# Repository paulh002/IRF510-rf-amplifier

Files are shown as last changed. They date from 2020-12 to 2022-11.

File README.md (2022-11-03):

# IRF510-rf-amplifier

This amplifier was designed as a pspice simulation project. Later I have build and tested it.
The goal was to see if sources of distortion could be found and how certain components infuence the linearity of the amplifier.
In the simulation schematic extra components are added to simulate loss in the transformers. Changing these loss components give rise to more or less distrortion
There are 2 versions of the PCB in Kicad direcory IRF510 is used in RD16HFF directory the RD16HFF is used, this Fet has a different layout, so take care to choose the correct version.
With R6 and R11 you can control the gain. R9 and R14 are there to add extra stability. You can experiment with the values or make R9 and R14 0 ohm.

Small 10 to 20 Watt ampliefier (2 - 30 Mhz) with driver

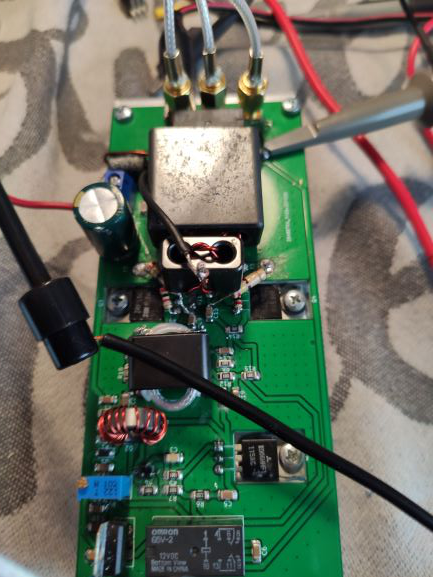
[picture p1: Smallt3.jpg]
VFO


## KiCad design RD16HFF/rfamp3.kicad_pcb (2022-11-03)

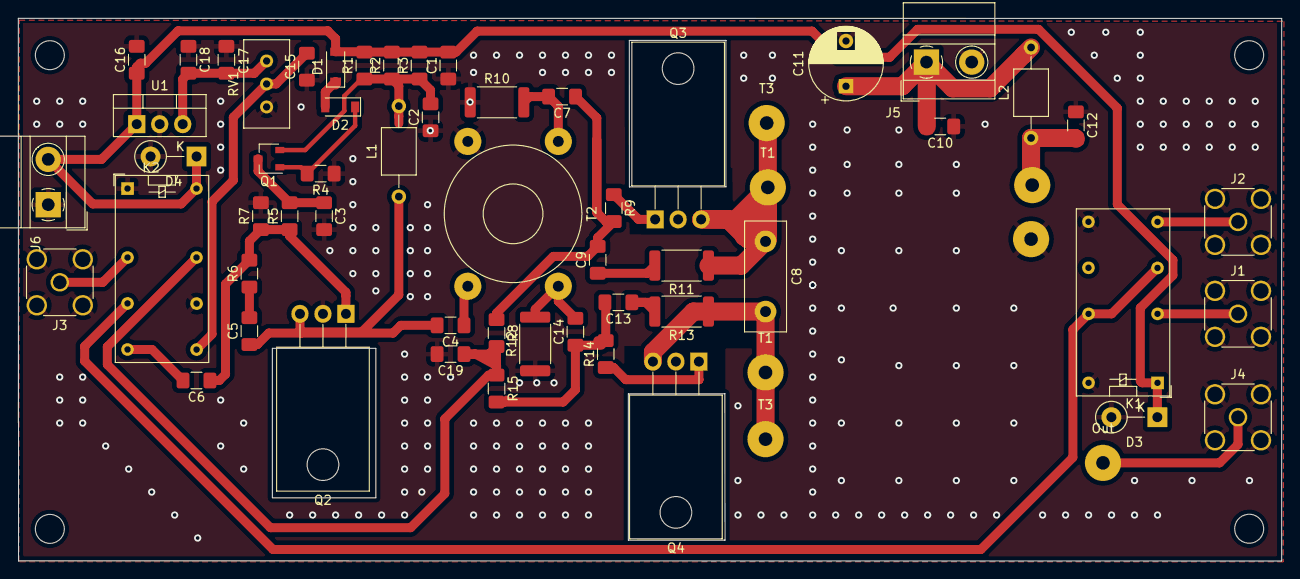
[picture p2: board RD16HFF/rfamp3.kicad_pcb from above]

Board: 2 copper layers, 139.6 x 60.0 mm, 66 parts (0 on the bottom side), 31 nets.

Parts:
 : SolderWirePad_1x01_Drill1.5mm
 #2: SolderWirePad_1x01_Drill1.5mm
 #3,  #4,  #5,  #6: MountingHole_3.2mm_M3
C1, C2, C4, C5, C6, C7, C9, C10, C12, C13, C14, C15, C18, C19: 100n; C_1206_3216Metric_Pad1.42x1.75mm_HandSolder
C3: 1u; C_1206_3216Metric_Pad1.42x1.75mm_HandSolder
C8: 500p; C_Disc_D12.0mm_W4.4mm_P7.75mm
C11: 100u; CP_Radial_D8.0mm_P5.00mm
C16, C17: 10u; C_1206_3216Metric_Pad1.42x1.75mm_HandSolder
D1, D2: D; D_SOD-123
D3, D4: D; D_DO-41_SOD81_P5.08mm_Vertical_KathodeUp
J1, J3: Conn_Coaxial; SMA_Amphenol_132134_Vertical
J2: LPF-Out; SMA_Amphenol_132134_Vertical
J4: LPF; SMA_Amphenol_132134_Vertical
J5: 12V Power; TerminalBlock_MetzConnect_Type011_RT05502HBWC_1x02_P5.00mm_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
J6: 12V Switch; TerminalBlock_MetzConnect_Type011_RT05502HBWC_1x02_P5.00mm_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
K1, K2: G5V-2; Relay_DPDT_Omron_G5V-2
L1, L2: 100u; L_Axial_L5.0mm_D3.6mm_P10.00mm_Horizontal_Murata_BL01RN1A2A2
Out: SolderWirePad_1x01_Drill1.5mm
Q1: 2N3906; SOT-23W
Q2: RD06HHF; TO-220-3_Horizontal_TabDown
Q3: RD16HHF; TO-220-3_Horizontal_TabDown
Q4: RD16HFF; TO-220-3_Horizontal_TabDown
R1, R2, R3: 10; R_1206_3216Metric_Pad1.42x1.75mm_HandSolder
R4, R5, R7, R8, R15: 1k; R_1206_3216Metric_Pad1.42x1.75mm_HandSolder
R6: 560; R_1206_3216Metric_Pad1.42x1.75mm_HandSolder
R9, R14: 4.7; R_1206_3216Metric_Pad1.42x1.75mm_HandSolder
R10: 22; R_2512_6332Metric
R11, R13: 220; R_2512_6332Metric
R12: 10; R_2512_6332Metric
RV1: R_POT; Potentiometer_Bourns_3296W_Vertical
T1, T1#2, T3, T3#2: SolderWirePad_1x01_Drill1.5mm
T2: Transformer_1P_1S; Transformer_Toroid_Horizontal_D14.0mm_Amidon-T50
U1: L7805; TO-220-3_Vertical

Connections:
12V_Switch: C1.2, C16.1, D1.2 (A), D3.1 (K), D4.1 (K), J6.2, K1.1, K2.16, R1.2, R2.2, R3.2, U1.1 (IN)
Bias_A: C19.1, K2.13, R8.2, R15.1
GND: .1, C1.1, C2.1, C3.2, C10.1, C11.2, C12.1, C15.1, C16.2, C17.2, C18.1, C19.2, D3.2 (A), D4.2 (A), J1.2 (Ext), J2.2 (Ext), J3.2 (Ext), J4.2 (Ext), J5.2, J6.1, K1.9, K1.16, K2.1, K2.11, Q2.2 (S), Q3.2 (S), Q4.2 (S), R4.1, R7.2, R10.1, R12.1, RV1.3, T2.1 (AA), U1.2 (GND)
unnamed: C2.2, L1.2, Q1.2 (E), R1.1, R2.1, R3.1
unnamed: C3.1, Q1.3 (C), R5.2
unnamed: C4.1, T2.2 (AB)
unnamed: C4.2, C5.1, L1.1, Q2.3 (D)
unnamed: C5.2, R6.1
unnamed: C6.1, Q2.1 (G), R5.1, R6.2, R7.1
unnamed: C6.2, K2.8
unnamed: C7.1, C9.2, R8.1, R9.2
unnamed: C7.2, R10.2, T2.3 (SA)
unnamed: C8.1, Q3.3 (D), R11.1, T1#2.1, T3.1
unnamed: C8.2, Q4.3 (D), R13.1, T1.1, T3#2.1
unnamed: C9.1, R11.2
unnamed: C10.2, C11.1, J5.1, L2.2
unnamed: #2.1, C12.2, L2.1
unnamed: C13.1, R13.2
unnamed: C13.2, C14.1, R14.2, R15.2
unnamed: C14.2, R12.2, T2.4 (SB)
unnamed: C15.2, K2.9, RV1.2
unnamed: C17.1, C18.2, RV1.1, U1.3 (OUT)
unnamed: D1.1 (K), D2.2 (A)
unnamed: D2.1 (K), Q1.1 (B), R4.2
unnamed: J1.1 (In), K1.4
unnamed: J2.1 (In), K1.8
unnamed: J3.1 (In), K2.4
unnamed: J4.1 (In), Out.1
unnamed: K1.6, K1.13, K2.6
unnamed: Q3.1 (G), R9.1
unnamed: Q4.1 (G), R14.1

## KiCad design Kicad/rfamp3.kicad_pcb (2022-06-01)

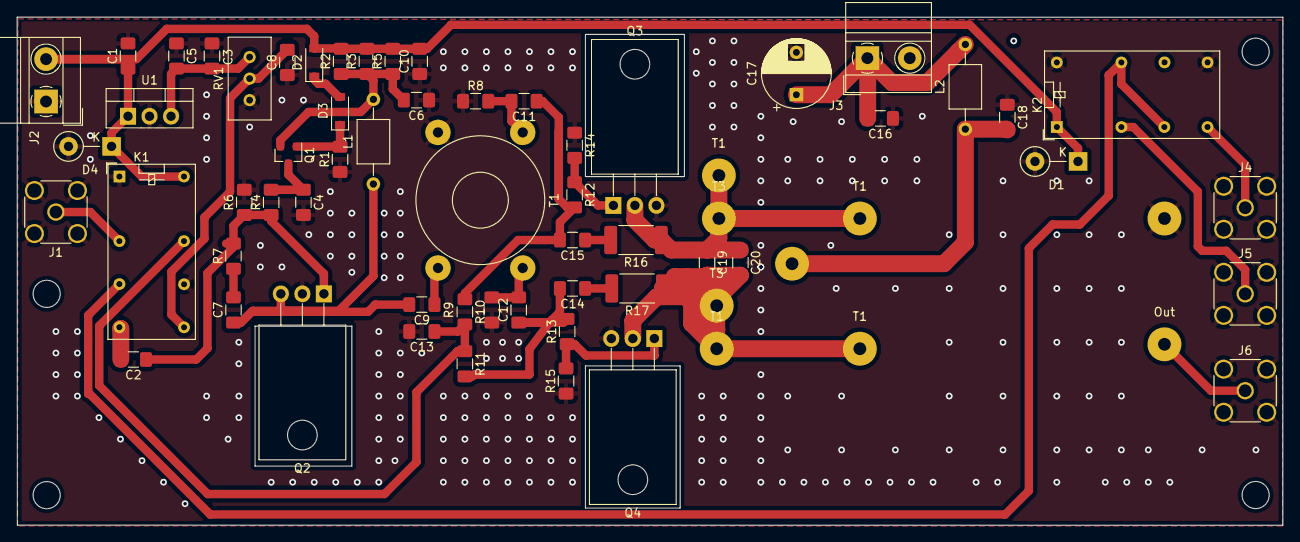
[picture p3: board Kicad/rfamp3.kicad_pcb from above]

Board: 2 copper layers, 149.4 x 60.0 mm, 71 parts (0 on the bottom side), 32 nets.

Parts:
 : MountingHole_3.2mm_M3
 #2,  #3,  #4: MountingHole_3.2mm_M3
 #5,  #6: SolderWirePad_1x01_Drill1.5mm
C1, C3: 10u; C_1206_3216Metric_Pad1.42x1.75mm_HandSolder
C2, C5, C6, C7, C8, C9, C10, C11, C12, C13, C14, C15, C16, C18: 100n; C_1206_3216Metric_Pad1.42x1.75mm_HandSolder
C4: 1u; C_1206_3216Metric_Pad1.42x1.75mm_HandSolder
C17: 100u; CP_Radial_D8.0mm_P5.00mm
C19, C20: 500p; C_1206_3216Metric_Pad1.42x1.75mm_HandSolder
D1, D4: 1n4007; D_DO-41_SOD81_P5.08mm_Vertical_KathodeUp
D2, D3: D; D_SOD-123
J1, J5: Conn_Coaxial; SMA_Amphenol_132134_Vertical
J2: 12V Switch; TerminalBlock_MetzConnect_Type011_RT05502HBWC_1x02_P5.00mm_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
J3: 12V Power; TerminalBlock_MetzConnect_Type011_RT05502HBWC_1x02_P5.00mm_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
J4: LPF-Out; SMA_Amphenol_132134_Vertical
J6: LPF; SMA_Amphenol_132134_Vertical
K1, K2: G5V-2; Relay_DPDT_Omron_G5V-2
L1, L2: 100u; L_Axial_L5.0mm_D3.6mm_P10.00mm_Horizontal_Murata_BL01RN1A2A2
Out: SolderWirePad_1x01_Drill1.5mm
Q1: 2N3906; SOT-23
Q2: RD6HHF1; TO-220-3_Horizontal_TabDown
Q3, Q4: IRF510; TO-220-3_Horizontal_TabDown
R1, R4, R6, R10, R11, R14, R15: 1k; R_1206_3216Metric_Pad1.42x1.75mm_HandSolder
R2, R3, R5, R8, R9: 10; R_1206_3216Metric_Pad1.42x1.75mm_HandSolder
R7: 560; R_1206_3216Metric_Pad1.42x1.75mm_HandSolder
R12, R13: 1; R_1206_3216Metric_Pad1.42x1.75mm_HandSolder
R16, R17: 220; R_2512_6332Metric_Pad1.52x3.35mm_HandSolder
RV1: R_POT; Potentiometer_Bourns_3296W_Vertical
T1: Transformer_1P_1S; Transformer_Toroid_Horizontal_D14.0mm_Amidon-T50
T1#2, T1#3, T1#4, T1#5, T3, T3#2: SolderWirePad_1x01_Drill1.5mm
U1: L7805; TO-220-3_Vertical

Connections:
12V_Switch: C1.1, C10.2, D1.1 (K), D2.2 (A), D4.1 (K), J2.2, K1.16, K2.1, R2.2, R3.2, R5.2, U1.1 (IN)
Bias_A: C13.1, K1.13, R10.2, R11.1
GND: #5.1, C1.2, C3.2, C4.2, C5.1, C6.1, C8.1, C10.1, C13.2, C16.1, C17.2, C18.1, D1.2 (A), D4.2 (A), J1.2 (Ext), J2.1, J3.2, J4.2 (Ext), J5.2 (Ext), J6.2 (Ext), K1.1, K1.11, K2.9, K2.16, Q2.2 (S), Q3.3 (S), Q4.3 (S), R1.1, R6.2, R8.1, R9.1, R14.1, R15.1, RV1.3, T1.1 (AA), U1.2 (GND)
unnamed: C2.1, Q2.1 (G), R4.1, R6.1, R7.2
unnamed: C2.2, K1.8
unnamed: C3.1, C5.2, RV1.1, U1.3 (OUT)
unnamed: C4.1, Q1.3 (C), R4.2
unnamed: C6.2, L1.2, Q1.2 (E), R2.1, R3.1, R5.1
unnamed: C7.1, C9.2, L1.1, Q2.3 (D)
unnamed: C7.2, R7.1
unnamed: C8.2, K1.9, RV1.2
unnamed: C9.1, T1.2 (AB)
unnamed: C11.1, C15.2, R10.1, R12.2
unnamed: C11.2, R8.2, T1.3 (SA)
unnamed: C12.1, C14.2, R11.2, R13.2
unnamed: #6.1, C12.2, R9.2, T1.4 (SB)
unnamed: C14.1, R17.2
unnamed: C15.1, R16.2
unnamed: C16.2, C17.1, J3.1, L2.2
unnamed: C18.2, L2.1
unnamed: C19.1, C20.1, Q3.2 (D), R16.1
unnamed: C19.2, C20.2, Q4.2 (D), R17.1
unnamed: T1#3.1, T1#4.1, T3.1
unnamed: T1#2.1, T1#5.1, T3#2.1
unnamed: D2.1 (K), D3.2 (A)
unnamed: D3.1 (K), Q1.1 (B), R1.2
unnamed: J1.1 (In), K1.4
unnamed: J4.1 (In), K2.8, Out.1
unnamed: J5.1 (In), K2.4
unnamed: K1.6, K2.6, K2.13
unnamed: Q3.1 (G), R12.1, R14.2
unnamed: Q4.1 (G), R13.1, R15.2

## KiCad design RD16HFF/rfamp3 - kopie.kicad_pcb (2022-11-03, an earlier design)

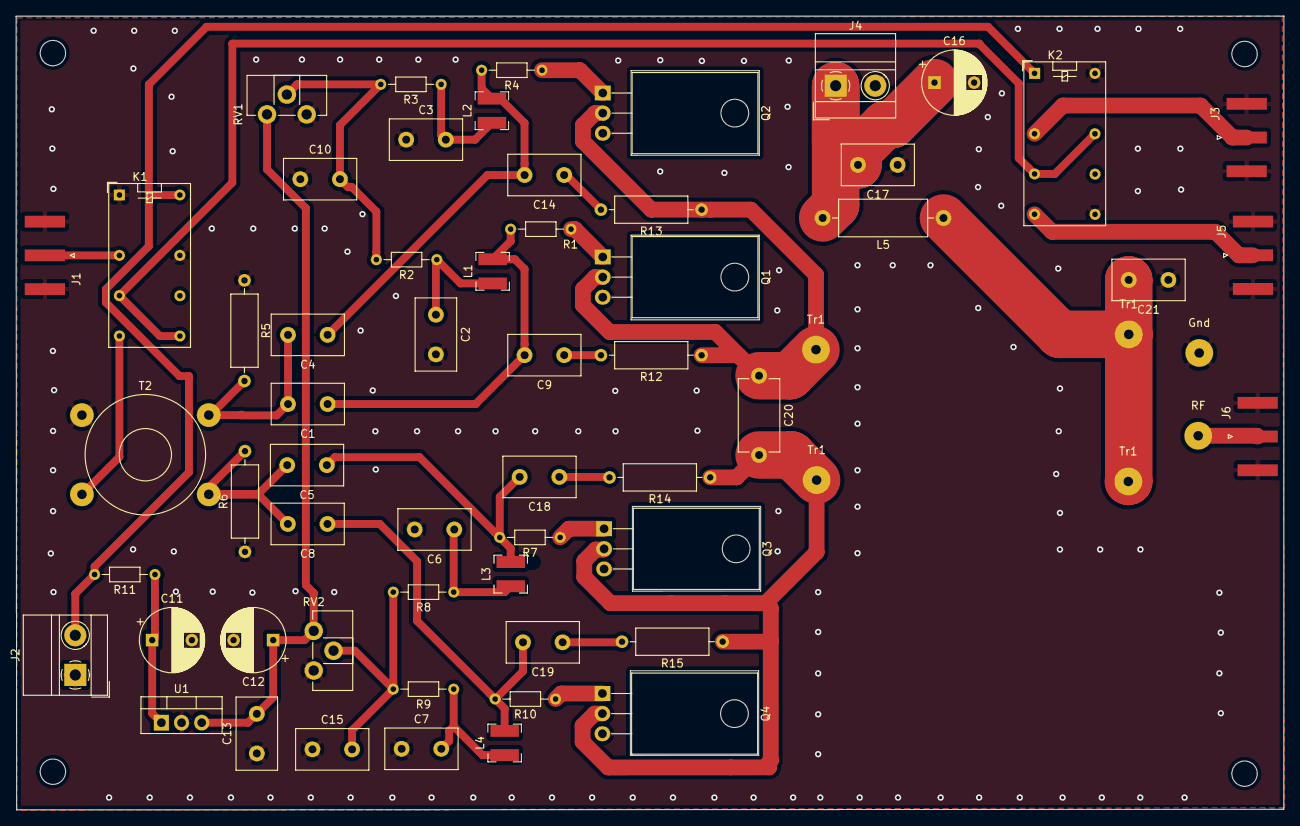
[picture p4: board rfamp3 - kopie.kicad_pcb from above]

Board: 2 copper layers, 159.9 x 100.1 mm, 67 parts (0 on the bottom side), 34 nets.

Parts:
 : MountingHole_3.2mm_M3
 #2,  #3,  #4: MountingHole_3.2mm_M3
C1, C2, C3, C4, C5, C6, C7, C8, C9, C10, C13, C14, C15, C17, C18, C19, C21: 100n; C_Disc_D9.0mm_W5.0mm_P5.00mm
C11, C12: 10u; CP_Radial_D8.0mm_P5.00mm
C16: 100u; CP_Radial_D8.0mm_P5.00mm
C20: 500p; C_Disc_D9.0mm_W5.0mm_P10.00mm
Gnd: Gnd; SolderWirePad_1x01_Drill1.2mm
J1, J3: Conn_Coaxial; SMA_Amphenol_132289_EdgeMount
J2: 12V Switch; TerminalBlock_MetzConnect_Type011_RT05502HBWC_1x02_P5.00mm_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
J4: 12V Power; TerminalBlock_MetzConnect_Type011_RT05502HBWC_1x02_P5.00mm_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
J5: LPF-Out; SMA_Amphenol_132289_EdgeMount
J6: LPF; SMA_Amphenol_132289_EdgeMount
K1, K2: G5V-2; Relay_DPDT_Omron_G5V-2
L1, L2, L3, L4: 100u; L_Bourns-SRN4018
L5: 100u; L_Axial_L11.0mm_D4.5mm_P15.24mm_Horizontal_Fastron_MECC
Q1, Q2, Q3, Q4: IRFN24; TO-220-3_Horizontal_TabDown
R1, R4, R7, R10: 4.7; R_Axial_DIN0204_L3.6mm_D1.6mm_P7.62mm_Horizontal
R2, R3, R8, R9: 47; R_Axial_DIN0204_L3.6mm_D1.6mm_P7.62mm_Horizontal
R5, R6: 10; R_Axial_DIN0309_L9.0mm_D3.2mm_P12.70mm_Horizontal
R11: 2.2k; R_Axial_DIN0204_L3.6mm_D1.6mm_P7.62mm_Horizontal
R12, R13, R14, R15: 220; R_Axial_DIN0309_L9.0mm_D3.2mm_P12.70mm_Horizontal
RF: Rf; SolderWirePad_1x01_Drill1.2mm
RV1, RV2: R_POT; Potentiometer_ACP_CA9-H2,5_Horizontal
T2: Input transformer; Transformer_Toroid_Horizontal_D14.0mm_Amidon-T50
Tr1, Tr1#2, Tr1#3, Tr1#4: Tr1; SolderWirePad_1x01_Drill1.2mm
U1: L7805; TO-220-3_Vertical

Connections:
12V_Switch: J2.2, K1.16, K2.1, R11.2
Bias_A: C10.2, R2.2, R3.2, RV1.2
Bias_B: C15.2, R8.2, R9.2, RV2.2
GND: C2.2, C3.1, C6.2, C7.1, C10.1, C11.2, C12.2, C13.1, C15.1, C16.2, C17.1, C21.1, Gnd.1, J1.2, J2.1, J3.2, J4.2, J5.2, J6.2, K1.1, K1.13, K2.9, K2.16, Q1.3, Q2.3, Q3.3, Q4.3, R5.1, R6.1, RV1.3, RV2.3, T2.3, U1.2
unnamed: C1.1, C9.2, L1.1, R1.2
unnamed: C1.2, C4.2, R5.2, T2.4
unnamed: C2.1, L1.2, R2.1
unnamed: C3.2, L2.2, R3.1
unnamed: C5.2, C8.2, R6.2, T2.2
unnamed: C6.1, L3.2, R8.1
unnamed: C7.2, L4.2, R9.1
unnamed: C9.1, R12.2
unnamed: C11.1, R11.1, U1.1
unnamed: C12.1, C13.2, RV1.1, RV2.1, U1.3
unnamed: C14.1, R13.2
unnamed: C4.1, C14.2, L2.1, R4.2
unnamed: C16.1, C17.2, J4.1, L5.2
unnamed: C18.1, R14.2
unnamed: C5.1, C18.2, L3.1, R7.2
unnamed: C19.1, R15.2
unnamed: C8.1, C19.2, L4.1, R10.2
unnamed: C20.1, Q1.2, Q2.2, R12.1, R13.1, Tr1#2.1
unnamed: C20.2, Q3.2, Q4.2, R14.1, R15.1, Tr1.1
unnamed: C21.2, L5.1, Tr1#3.1, Tr1#4.1
unnamed: J1.1, K1.4
unnamed: J3.1, K2.4
unnamed: J5.1, K2.8
unnamed: J6.1, RF.1
unnamed: K1.6, K1.9, K2.6, K2.13
unnamed: K1.8, T2.1
unnamed: Q1.1, R1.1
unnamed: Q2.1, R4.1
unnamed: Q3.1, R7.1
unnamed: Q4.1, R10.1

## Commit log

2022-06-01 add fly back diode
    [rfamp3-B_Cu.gbr, rfamp3-B_Mask.gbr, rfamp3-B_Paste.gbr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]
2022-11-03 add RD16HFF version
    [rfamp3 - kopie.kicad_pcb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]
